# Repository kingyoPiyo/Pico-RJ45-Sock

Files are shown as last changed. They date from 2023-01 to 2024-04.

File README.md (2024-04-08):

# Pico-RJ45-Sock

RJ45 connector for Raspberry Pi Pico.  
10BASE-T communication using Raspberry Pi Pico's PIO and software stack.  
See also : [Pico-10BASE-T](https://github.com/kingyoPiyo/Pico-10BASE-T "Pico-10BASE-T")

## Board Layout
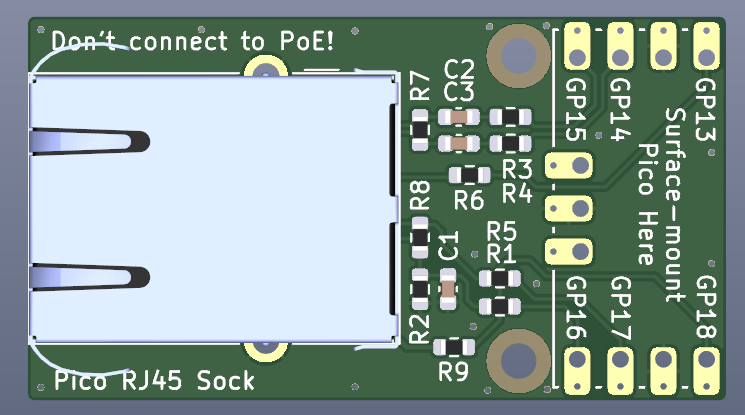
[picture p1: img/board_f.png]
  
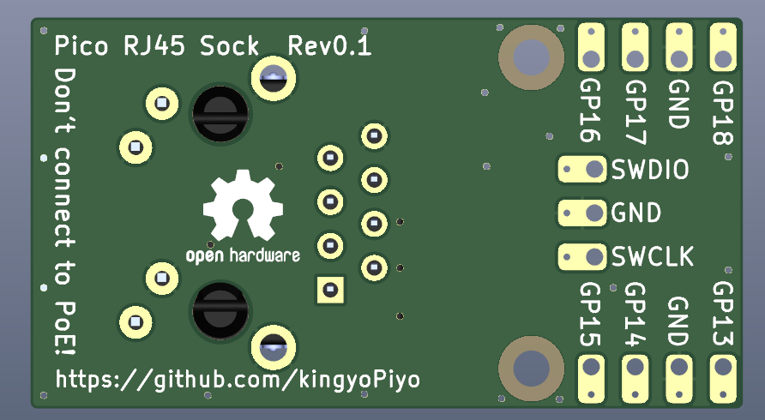
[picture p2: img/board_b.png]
  

## Assembly
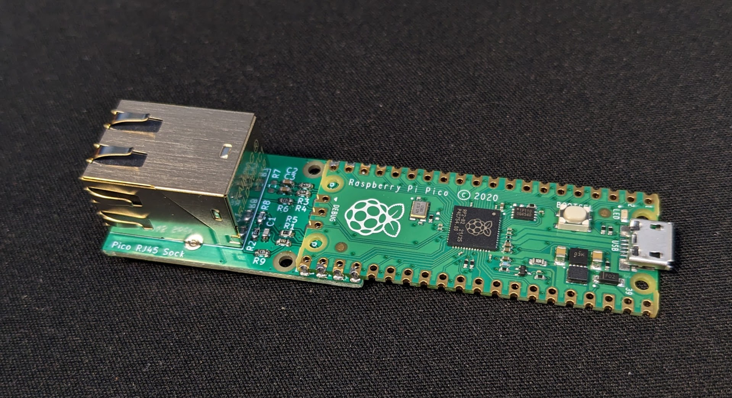
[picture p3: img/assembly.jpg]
  

## Schematic
[pico_rj45.pdf](kicad/pico_rj45.pdf "Schematic")

## Sample Firmware
| Link | Description |
| ---- | ---- |
| [Hello World](firmware/hello_world/ "hello_world") | ARP, UDP, ICMP Test.<br>Change *system.h* for connection settings.|
| [VBAN](firmware/vban/ "vban") | ARP, UDP, ICMP & VBAN Audio Streaming from ADC0, ADC1.<br>Change *system.h* for connection settings.<br>Please refer [here](doc/vban_preamp/VBAN_PreAmp.png "VBAN_PreAmp.png") for the preamplifier for ADC.|

## Quick-start

### pico-sdk install
See also : https://github.com/raspberrypi/pico-sdk
```
sudo apt install cmake gcc-arm-none-eabi libnewlib-arm-none-eabi libstdc++-arm-none-eabi-newlib build-essential
git clone https://github.com/raspberrypi/pico-sdk
cd pico-sdk
git submodule update --init
```
### Hello world Compile
```
git clone https://github.com/kingyopiyo/Pico-RJ45-Sock
cd Pico-RJ45-Sock/firmware/hello_world
mkdir build
cd build
cmake ..
make
```

## Reference
* Pico DVI Sock https://github.com/Wren6991/Pico-DVI-Sock
* pico_eth https://github.com/holysnippet/pico_eth_doc

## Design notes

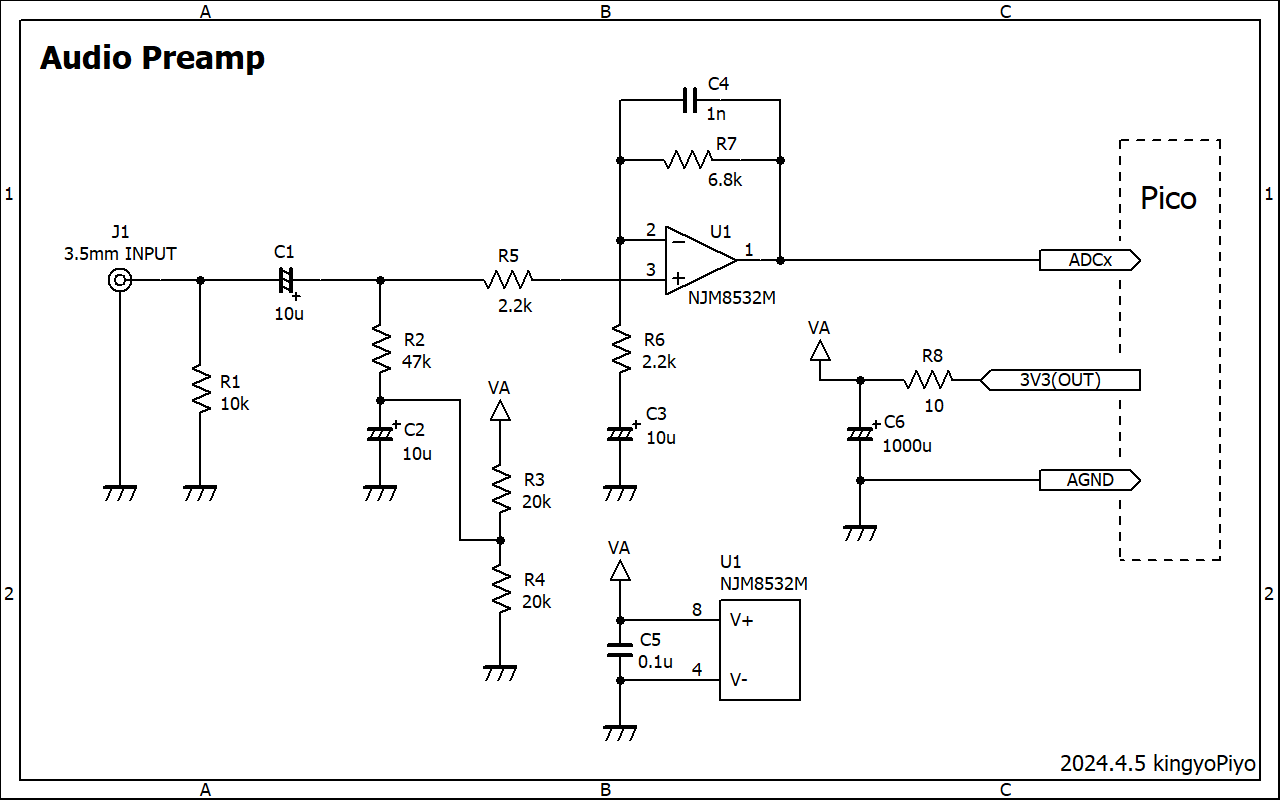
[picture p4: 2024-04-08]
doc/vban_preamp/VBAN_PreAmp.png

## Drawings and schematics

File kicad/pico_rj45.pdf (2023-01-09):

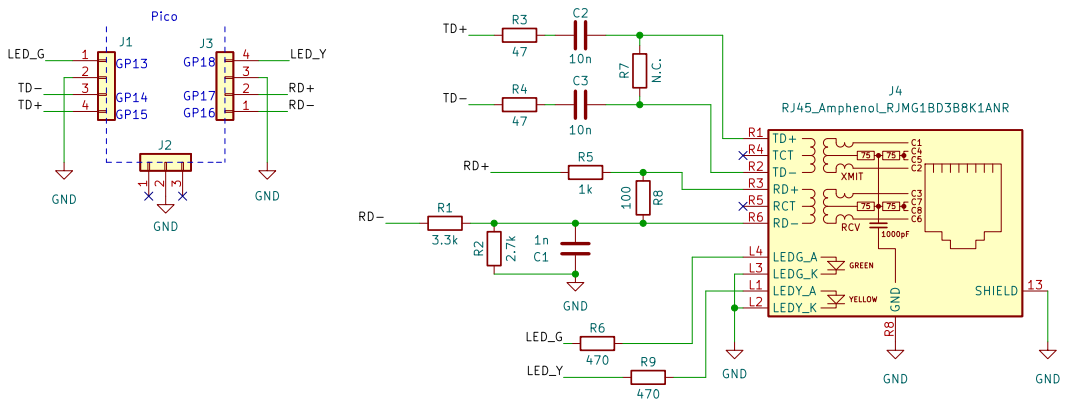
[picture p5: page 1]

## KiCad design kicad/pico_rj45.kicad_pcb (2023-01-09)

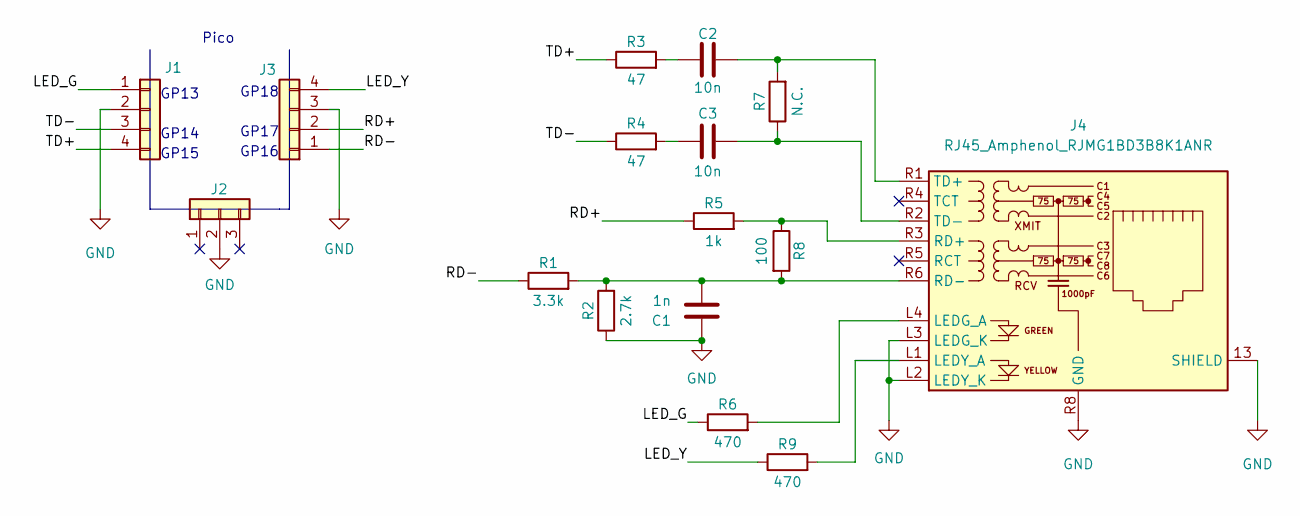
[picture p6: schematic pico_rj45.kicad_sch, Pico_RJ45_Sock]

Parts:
C1: 1n; C_0603_1608Metric
C2, C3: 10n; C_0603_1608Metric
J1, J3: Conn_01x04; castellated_2.54mm_smd_x4
J2: Conn_01x03; castellated_2.54mm_smd_x3
J4: RJ45_Amphenol_RJMG1BD3B8K1ANR
R1: 3.3k; R_0603_1608Metric
R2: 2.7k; R_0603_1608Metric
R3, R4: 47; R_0603_1608Metric
R5: 1k; R_0603_1608Metric
R6, R9: 470; R_0603_1608Metric
R7: N.C.; R_0603_1608Metric
R8: 100; R_0603_1608Metric

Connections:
/LED_G: J1.1, R6.1
/LED_Y: J3.4, R9.1
/RD+: J3.2, R5.1
/RD-: J3.1, R1.1
/TD+: J1.4, R3.1
/TD-: J1.3, R4.1
GND: C1.1, J1.2, J2.2, J3.3, J4.13 (SHIELD), J4.L2 (LEDY_K), J4.L3 (LEDG_K), J4.R8 (GND), R2.1
unnamed: C1.2, J4.R6 (RD-), R1.2, R2.2, R8.2
unnamed: C2.2, R3.2
unnamed: C3.2, R4.2
unnamed: J4.L1 (LEDY_A), R9.2
unnamed: J4.L4 (LEDG_A), R6.2
unnamed: C2.1, J4.R1 (TD+), R7.2
unnamed: C3.1, J4.R2 (TD-), R7.1
unnamed: J4.R3 (RD+), R5.2, R8.1

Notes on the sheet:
GP13
GP17
GP16
GP15
Pico
GP14
GP18

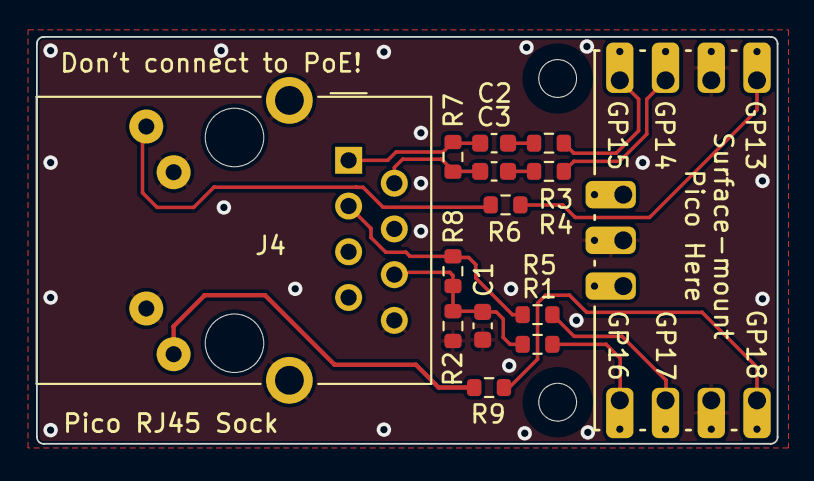
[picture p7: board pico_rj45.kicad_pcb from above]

Board: 2 copper layers, 41.1 x 22.6 mm, 16 parts (0 on the bottom side), 15 nets.

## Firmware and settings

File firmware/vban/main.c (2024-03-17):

/********************************************************
* Title    : Pico-10BASE-T VBAN Sample
* Date     : 2024/03/15
* Design   : kingyo
********************************************************/
#include <stdio.h>
#include "pico/stdlib.h"
#include "hwinit.h"
#include "eth.h"
#include "vban.h"
#include "oled.h"

int main() {
    uint8_t lv_l = 0, lv_r = 0;
    uint32_t lp_cnt = 0;
    uint32_t packet_cnt = 0;
    bool max_rst = true;

    stdio_init_all();
    hw_init();
    oled_init();
    eth_init();
    vban_init();
    
    printf("[BOOT]\r\n");

    hw_start_led_blink();

    uint32_t time = time_us_32();

    while (1) {
        packet_cnt += eth_main();
        packet_cnt += vban_main(&lv_l, &lv_r, max_rst);

        // 40ms Interval
        if (time_us_32() - time > 40000) {
            time = time_us_32();
            packet_cnt = packet_cnt / 2;
            if (packet_cnt > 64) packet_cnt = 64;
            oled_main(lv_l, lv_r, (uint8_t)packet_cnt);
            packet_cnt = 0;
            max_rst = true;
        } else {
            max_rst = false;
        }

        lp_cnt++;
    }
}

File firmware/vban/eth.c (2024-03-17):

#include <stdio.h>
#include "pico/stdlib.h"
#include "pico/multicore.h"
#include "hardware/irq.h"
#include "hardware/pio.h"
#include "hardware/dma.h"
#include "system.h"
#include "eth.h"
#include "arp.h"
#include "icmp.h"
#include "udp.h"
#include "ser_10base_t.pio.h"
#include "des_10base_t.pio.h"


// Define
#define HW_PINNUM_RXP           (17)            // Ethernet RX+
#define HW_PINNUM_RXN           (16)            // Ethernet RX-
#define HW_PINNUM_TXP           (15)            // Ethernet TX+
#define HW_PINNUM_TXN           (14)            // Ethernet TX-
#define HW_PINNUM_LED_G         (13)            // Ethernet LED G
#define HW_PINNUM_LED_Y         (18)            // Ethernet LED Y

#define HW_PINNUM_OUT0          (1)             // SMA OUT0 for Debug
#define HW_PINNUM_OUT1          (0)             // SMA OUT0 for Debug
#define DEF_NFLP_INTERVAL_US    (16000)         // NLP/FLP interval = 16ms +/- 8ms
#define DEF_DMY_INTERVAL_US     (1000000)       // Dummy Data send interval
#define DEF_LINK_TIMEOUT_US     (400000)        // Link down time out

#define DEF_ETHTYPE_IPV4        (0x0800)        // EtherType : IPv4
#define DEF_ETHTYPE_ARP         (0x0806)        // EtherType : ARP
#define DEF_ARPOPC_REQUEST      (0x0001)        // ARP Opcode : Request
#define DEF_ARPOPC_REPLY        (0x0002)        // ARP Opcode : Reply

#define DEF_IP_PROTOCOL_ICMP    (0x01)
#define DEF_IP_PROTOCOL_TCP     (0x06)
#define DEF_IP_PROTOCOL_UDP     (0x11)


// Global
static PIO pio_serdes = pio0;
static uint sm_tx = 0;
static uint sm_rx = 1;
volatile static uint32_t gsram[8][512]; // RX data buffer for Core0 and 1
static uint32_t tx_buf_udp[DEF_UDP_BUF_SIZE+1] = {0};
static uint32_t tx_buf_arp[DEF_ARP_BUF_SIZE+1] = {0};
static uint32_t tx_buf_icmp[DEF_ICMP_BUF_SIZE+1] = {0};

static const uint32_t pico_ip_addr = (DEF_SYS_PICO_IP1 << 24) +
                                     (DEF_SYS_PICO_IP2 << 16) +
                                     (DEF_SYS_PICO_IP3 << 8) +
                                     (DEF_SYS_PICO_IP4 << 0);

static uint32_t time_nflp = 0;


// Prototype
static void __time_critical_func(rx_func_core1)(void);
static void _clear_nflp_timer_cnt(void);
static bool _send_link_pulse(void);
static void _send_nlp(void);
static void _send_flp(uint16_t data);
static bool _send_udp(void);
static void _busy_led_update(bool led_on);
static void _rx_packets_proc(void);


// DMA
static uint32_t dma_ch_10base_t;
dma_channel_config dma_conf_10base_t;


void eth_init(void) {
    udp_init();
    arp_init();
    icmp_init();

    // 10BASE-T Serializer PIO init. Pin numbers must be sequential.
    uint offset = pio_add_program(pio_serdes, &ser_10base_t_program);
    ser_10base_t_program_init(pio_serdes, sm_tx, offset, HW_PINNUM_TXN);

    // LED
    gpio_init(HW_PINNUM_LED_G);
    gpio_set_dir(HW_PINNUM_LED_G, GPIO_OUT);
    gpio_init(HW_PINNUM_LED_Y);
    gpio_set_dir(HW_PINNUM_LED_Y, GPIO_OUT);

    gpio_put(HW_PINNUM_LED_G, true);
    gpio_put(HW_PINNUM_LED_Y, true);
    sleep_ms(300);
    gpio_put(HW_PINNUM_LED_G, false);
    gpio_put(HW_PINNUM_LED_Y, false);

    // Wait for Link up....
    for (uint32_t i = 0; i < 200;) {
        if (_send_link_pulse()) i++;
    }
    
    // RX
    gpio_init(HW_PINNUM_RXP);   gpio_set_dir(HW_PINNUM_RXP, GPIO_IN);       // Ethernet RX+
    gpio_set_input_hysteresis_enabled(HW_PINNUM_RXP, false);
    gpio_init(HW_PINNUM_RXN);   gpio_set_dir(HW_PINNUM_RXN, GPIO_OUT);      // Ethernet RX-
    gpio_put(HW_PINNUM_RXN, true);

    gpio_init(HW_PINNUM_OUT0);  gpio_set_dir(HW_PINNUM_OUT0, GPIO_OUT);     // SMA Out for Debug
    gpio_init(HW_PINNUM_OUT1);  gpio_set_dir(HW_PINNUM_OUT1, GPIO_OUT);     // SMA Out for Debug
    offset = pio_add_program(pio_serdes, &des_10base_t_program);
    des_10base_t_program_init(pio_serdes, sm_rx, offset, HW_PINNUM_RXP, HW_PINNUM_OUT0);
    multicore_launch_core1(rx_func_core1);

    // DMA
    dma_ch_10base_t = dma_claim_unused_channel(true);
    dma_conf_10base_t = dma_channel_get_default_config(dma_ch_10base_t);
    channel_config_set_dreq(&dma_conf_10base_t, pio_get_dreq(pio_serdes, sm_tx, true));
    channel_config_set_transfer_data_size(&dma_conf_10base_t, DMA_SIZE_32);
    channel_config_set_read_increment(&dma_conf_10base_t, true);
    channel_config_set_write_increment(&dma_conf_10base_t, false);
}


// RUN at Core0
uint32_t eth_main(void) {
    uint32_t ret = 0;

    _send_link_pulse();         // Link Pulse
    _busy_led_update(false);    // Busy LED (RJ45)

    // RX Buffer check
    if (multicore_fifo_rvalid()) {
        _rx_packets_proc();
        _busy_led_update(true);
        ret = 1;
    } else {
        // _send_udp();
    }

    return ret;
}


// Analysis and processing of incoming packets
void _rx_packets_proc(void) {
    uint32_t pop_data = multicore_fifo_pop_blocking();  // index num
    uint32_t slot = pop_data & 0x7; // 0 ~ 7
    uint32_t size = pop_data >> 3;  // x 32bit
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

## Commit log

2023-01-09 Add some files
    [pico_rj45.kicad_pcb, pico_rj45.kicad_sch]
2023-12-10 Use DMA for CRC Calc
2023-12-10 DMA対応
2023-12-10 Linkパルスの送信タイミング他改善
2023-12-10 PIOクロックの分周設定値を自動計算するようにした
2023-12-10 コンパイルエーラ対策
2023-12-28 Add ip address filter
2024-03-16 TX pin drive strength up.
2024-03-16 とりあえず動作
2024-03-16 ADCのバッファをリングバッファに変更
2024-04-08 Add Schematic.
